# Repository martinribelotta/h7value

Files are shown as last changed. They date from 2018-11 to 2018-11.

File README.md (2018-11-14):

# STM32H7 value line small board

Simple board for stm32h750 value line device in LQFP100 package.

> Require KiCAD 5.0 or higer

#### Design rules:

- Track/Clearance width: 8mils/8mils
- Drill dia: 0.3048 mm
- Via dia: 0.4064 mm

#### Board contents:

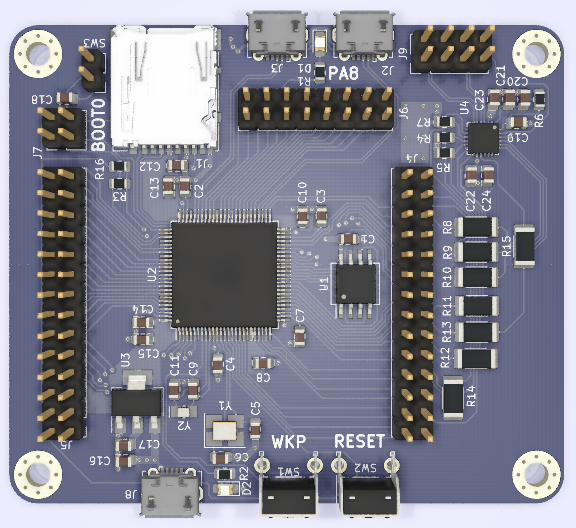
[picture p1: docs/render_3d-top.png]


- STM32H750VBT6: 1MBy RAM, 128KBy Flash at 400MHz CPU
- External flash in QSPI1 interface with execute in place (4, 8 or 16MBytes)
- USB HS and FS
- Ethernet PHY in RMII interface (optional)
- MicroSD card in 1bit interface
- 8MHz main crystal
- 32.768KHz RTC crystal
- SWD connector
- Reset button
- User button connected to PA13-WakeUP
- User led connected to PA8
- BOOT dip switch
- 800mA 3.3v regulator
- Others GPIO connected to 100mils-space pin header

#### Dimensions:

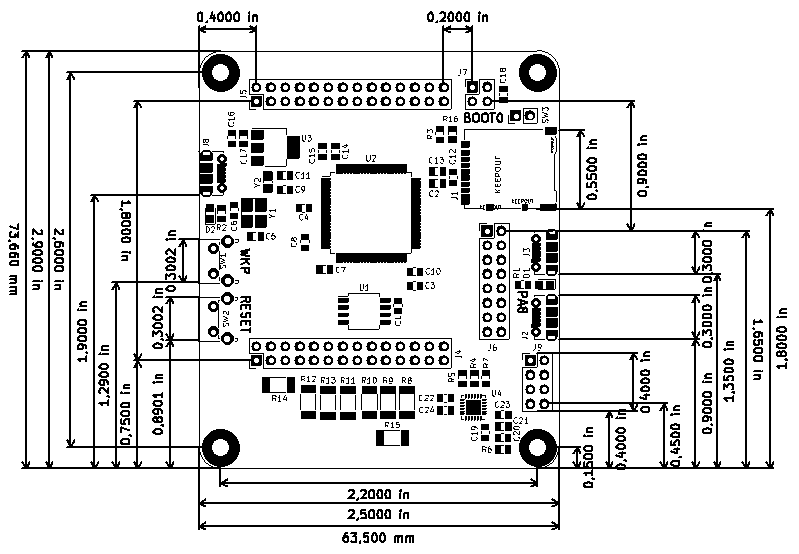
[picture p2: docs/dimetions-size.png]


#### Schematics:

Schematics

#### BOM and Gerbers

- [ ] BOM: TODO
- [ ] Gerber: TODO

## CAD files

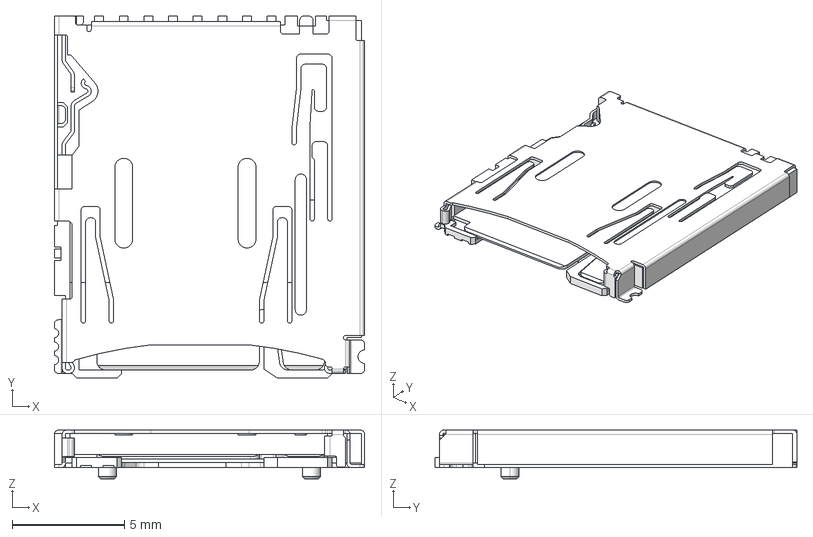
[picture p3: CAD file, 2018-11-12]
3d/DM3AT-SF-PEJ2M5.stp
13.8 x 16.2 x 2.18 mm

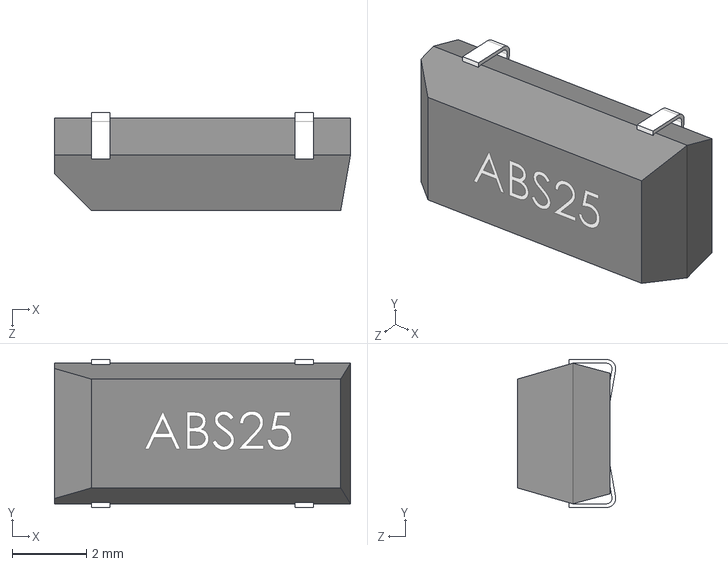
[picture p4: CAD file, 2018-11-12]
3d/ABS25.STEP
8.00 x 4.00 x 2.66 mm

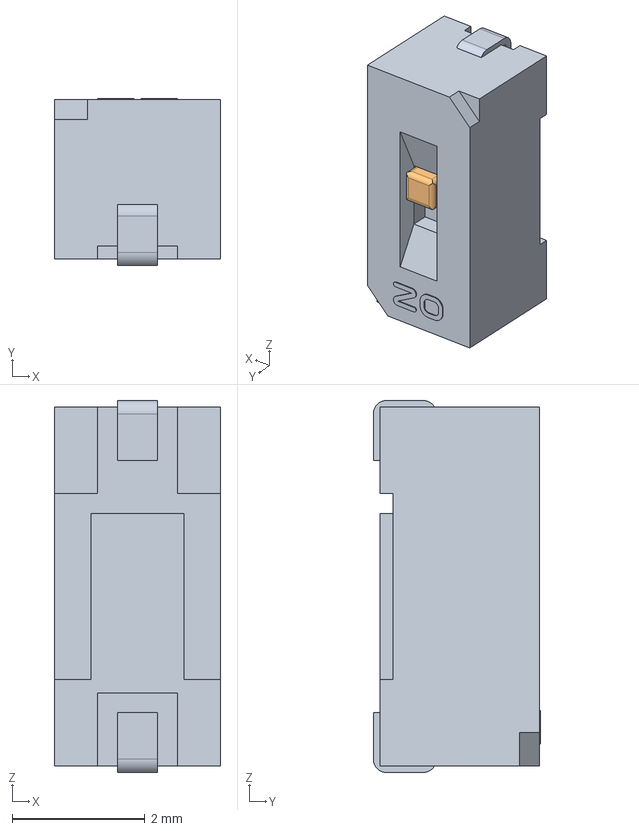
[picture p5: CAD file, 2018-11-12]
3d/CHS-01TA.stp
2.50 x 2.52 x 5.60 mm
_CHS-01-J-body
_CHS-slider

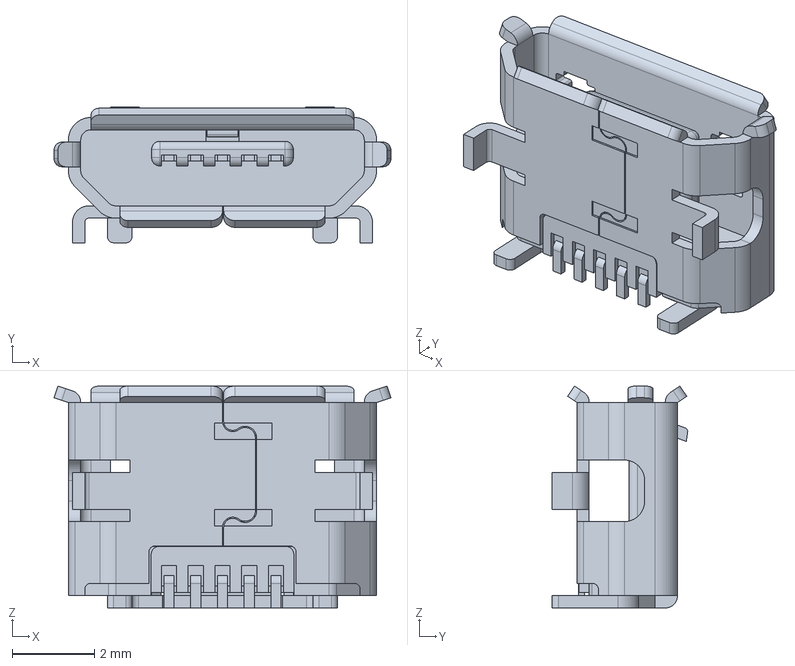
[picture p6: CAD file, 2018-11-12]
3d/1050170001.stp
8.20 x 3.30 x 5.40 mm

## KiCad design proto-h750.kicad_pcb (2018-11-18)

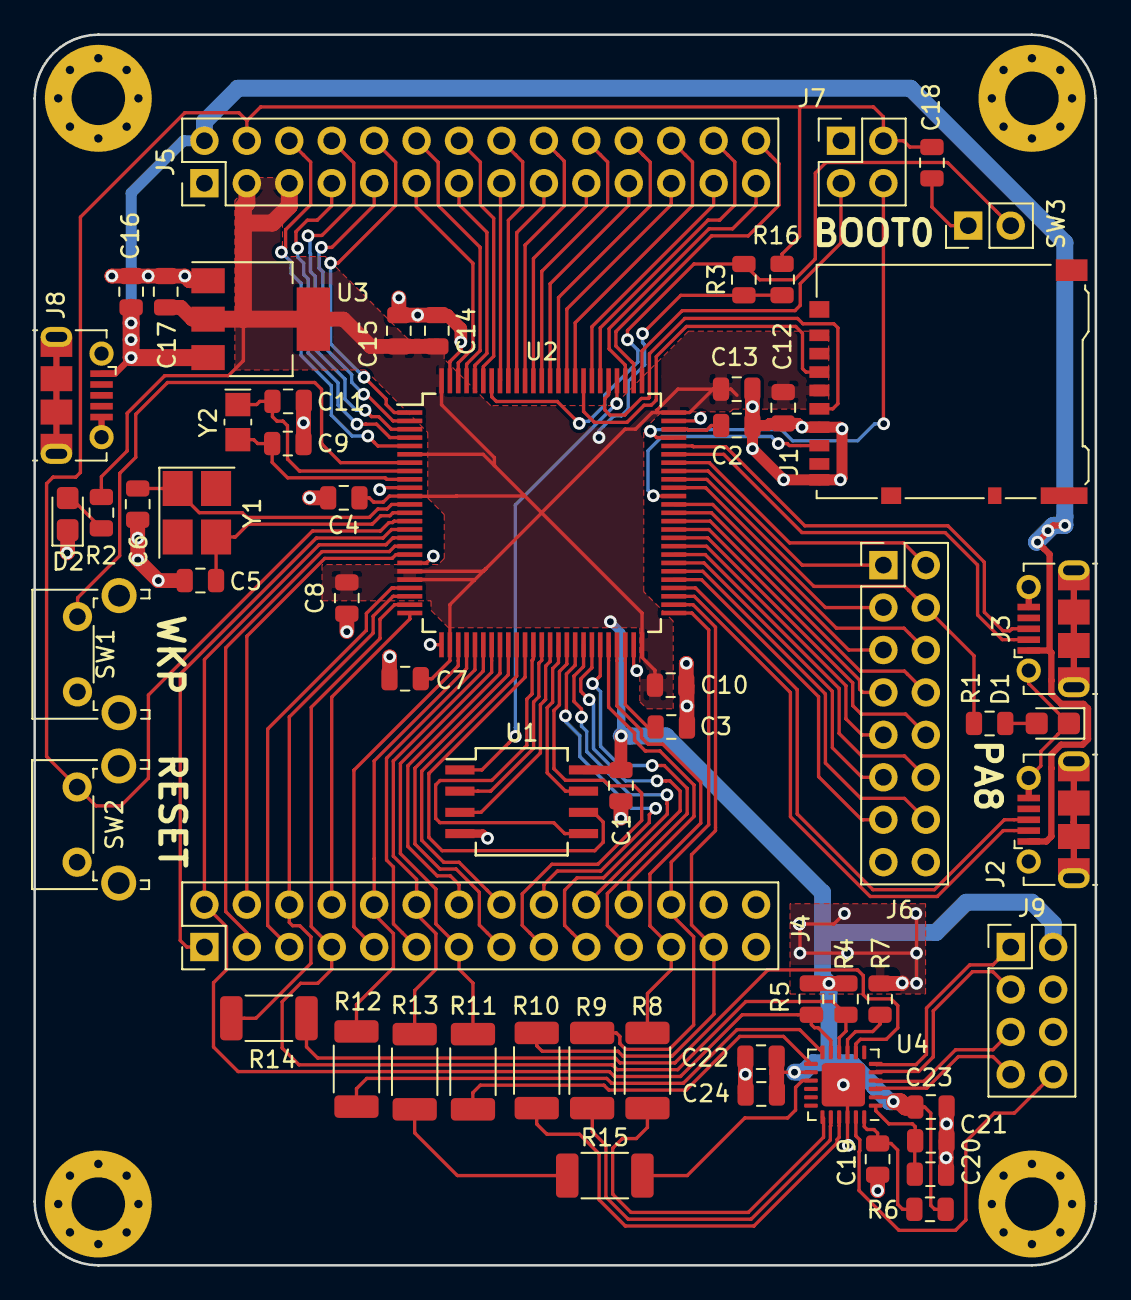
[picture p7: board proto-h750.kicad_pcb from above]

Board: 2 copper layers, 63.5 x 73.7 mm, 64 parts (0 on the bottom side), 107 nets.

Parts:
C1, C2, C3, C4, C7, C8, C10, C12, C13, C14, C18, C19, C22, C23: 100n; C_0805_2012Metric
C5, C6, C9, C11: 18p; C_0805_2012Metric
C15, C21, C24: 4.7u; C_0805_2012Metric
C16, C17: 10u; C_0805_2012Metric
C20: 2.2u; C_0805_2012Metric
D1, D2: RED; LED_0805_2012Metric_Castellated
H1, H2, H3, H4: MountingHole_Pad; MountingHole_3.2mm_M3_Pad_Via
J1: Micro_SD_Card; microSD_HC_Hirose_DM3AT-SF-PEJM5
J2, J3, J8: USB_B_Micro; USB_Micro-B_Molex-105017-0001
J4, J5: Conn_02x14_Odd_Even; PinHeader_2x14_P2.54mm_Vertical
J6: Conn_02x08_Odd_Even; PinHeader_2x08_P2.54mm_Vertical
J7: Conn_02x02_Odd_Even; PinHeader_2x02_P2.54mm_Vertical
J9: Conn_02x04_Odd_Even; PinHeader_2x04_P2.54mm_Vertical
R1, R2: 220R; R_0805_2012Metric
R3, R4, R5, R6, R16: 10K; R_0805_2012Metric
R7: 6.49K 1%; R_0805_2012Metric
R8, R9, R10, R11, R12, R13, R14, R15: 0R; R_2010_5025Metric
SW1, SW2: SW_Push; SW_Tactile_SPST_Angled_PTS645Vx31-2LFS
SW3: SW_DIP_x01; PinHeader_1x02_P2.54mm_Vertical
U1: S25FL132K0XMFI010; SO-8_5.3x6.2mm_P1.27mm
U2: STM32H750VBT6; LQFP-100_14x14mm_P0.5mm
U3: AP1117-33; SOT-223-3_TabPin2
U4: KSZ8081RNA; QFN-24-1EP_4x4mm_P0.5mm_EP2.6x2.6mm
Y1: 16MHz; Crystal_SMD_3225-4Pin_3.2x2.5mm_HandSoldering
Y2: 32.768KHz; Crystal_SMD_MicroCrystal_CC8V-T1A-2Pin_2.0x1.2mm_HandSolder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

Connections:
+5V: C16.2, J2.1, J3.1, J5.2, J8.1, U3.3
/BOOT: R3.2, SW3.2, U2.94
/ENET_CLK: R14.1, U4.8
/ENET_CRSDV: R15.2, U4.15
/ENET_MDC: J4.2, R5.2, U2.16, U4.11
/ENET_MDIO: J4.7, R4.2, U2.24, U4.10
/ENET_RXD0: R11.1, U4.13
/ENET_RXD1: R12.1, U4.12
/ENET_TXD0: R9.1, U4.20
/ENET_TXD1: R10.1, U4.21
/ENET_TXEN: R8.1, U4.19
/ETH_LED: J9.8, U4.23
/ETH_RX+: J9.5, U4.4
/ETH_RX-: J9.7, U4.3
/ETH_TX+: J9.1, U4.6
/ETH_TX-: J9.3, U4.5
/IO0: U1.5, U2.37
/IO1: U1.2, U2.38
/IO2: U1.3, U2.39
/IO3: U1.7, U2.40
/PA0: J4.5, U2.22
/PA1: J4.6, R14.2, U2.23
/PA3: J4.8, U2.25
/PA4: J4.9, U2.28
/PA5: J4.10, R12.2, U2.29
/PA6: J4.11, U2.30
/PA7: J4.12, R13.2, U2.31
/PA8: J6.4, R1.2, U2.67
/PA9: J6.1, U2.68
/PA10: J6.2, U2.69
/PA15: J5.28, U2.77
/PB0: J4.15, U2.34
/PB1: J4.16, U2.35
/PB3: J5.19, U2.89
/PB4: J5.18, U2.90
/PB5: J5.17, U2.91
/PB6: J5.16, U2.92
/PB7: J5.15, U2.93
/PB8: J5.14, U2.95
/PB9: J5.13, U2.96
/PB10: J4.22, U2.46
/PB11: J4.23, R8.2, U2.47
/PB12: J4.24, R9.2, U2.51
/PB13: J4.25, R10.2, U2.52
/PC0: J4.1, U2.15
/PC2: J4.3, U2.17
/PC3: J4.4, U2.18
/PC4: J4.13, R11.2, U2.32
/PC5: J4.14, U2.33
/PC6: J6.5, U2.63
/PC7: J6.6, U2.64
/PC9: J6.3, U2.66
/PC10: J5.27, U2.78
/PC13: SW1.2, U2.7
/PD0: J5.26, U2.81
/PD1: J5.25, U2.82
/PD3: J5.24, U2.84
/PD4: J5.23, U2.85
/PD5: J5.22, U2.86
/PD6: J5.21, U2.87
/PD7: J5.20, U2.88
/PD8: J6.13, U2.55
/PD9: J6.14, U2.56
/PD10: J6.11, U2.57
/PD11: J6.12, U2.58
/PD12: J6.9, U2.59
/PD13: J6.10, U2.60
/PD14: J6.7, U2.61
/PD15: J6.8, U2.62
/PE0: J5.12, U2.97
/PE1: J5.11, U2.98
/PE2: J5.10, U2.1
/PE3: J5.9, U2.2
/PE4: J5.8, U2.3
/PE5: J5.7, U2.4
/PE6: J5.6, U2.5
/PE11: J4.17, U2.41
/PE12: J4.18, U2.42
/PE13: J4.19, U2.43
/PE14: J4.20, U2.44
/PE15: J4.21, U2.45
/SCLK: U1.6, U2.36
/SD_CK: J1.5, U2.80
/SD_CMD: J1.3, U2.83
/SD_D0: J1.7, U2.65
/SWCLK: J7.3, U2.76
/SWDIO: J7.4, U2.72
/USB0_D+: J2.3, U2.54
/USB0_D-: J2.2, U2.53
/USB1_D+: J3.3, U2.71
/USB1_D-: J3.2, U2.70
/nCS: U1.1, U2.79
/nRESET: C18.1, J5.4, J7.2, R16.2, SW2.2, U2.14
GND: C1.2, C2.2, C3.2, C4.2, C5.1, C6.1, C7.2, C8.2, C9.1, C10.2, C11.1, C12.2, C13.2, C14.1, C15.2, C16.1, C17.2, C18.2, C19.1, C20.1, C21.1, C22.1, C23.1, C24.1, D1.1, D2.1, H1.1, H2.1, H3.1, H4.1, J1.6, J1.9, J2.5, J2.6, J3.5, J3.6, J4.26, J4.27, J4.28, J5.1, J6.15, J6.16, J7.1, J8.5, J8.6, J9.4, J9.6, R7.1, SW1.1, SW2.1, SW3.1, U1.4, U2.10, U2.19, U2.26, U2.49, U2.74, U2.99, U3.1, U4.22, U4.25
unnamed: C2.1, U2.73
unnamed: C3.1, U2.48
unnamed: C5.2, U2.13, Y1.3
unnamed: C6.2, U2.12, Y1.1
unnamed: C9.2, U2.9, Y2.2
unnamed: C11.2, U2.8, Y2.1
unnamed: C19.2, R6.2, U4.24
unnamed: C20.2, C21.2, U4.1
unnamed: D1.2, R1.1
unnamed: D2.2, R2.1
unnamed: R7.2, U4.9
unnamed: R13.1, R15.1
VCC: C1.1, C4.1, C7.1, C8.1, C10.1, C12.1, C13.1, C14.2, C15.1, C17.1, C22.2, C23.2, C24.2, J1.4, J5.3, J5.5, J9.2, R2.2, R3.1, R4.1, R5.1, R6.1, R16.1, U1.8, U2.6, U2.11, U2.20, U2.21, U2.27, U2.50, U2.75, U2.100, U3.2, U4.2, U4.14

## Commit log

2018-11-14 Add eth phy
    [proto-h750.kicad_pcb, proto-h750.sch]
2018-11-14 Add README, create schematics and put measures in PCB
    [proto-h750.kicad_pcb]
2018-11-16 Change dimention annotations
    [proto-h750.kicad_pcb]
2018-11-18 Prepare to BOM
    - Change BOOT switch by jumper
    - Change 32.768KHz footprint by 2SMD 2.0x1.2mm
    - Change 8MHz 4SMD by same footprint in 16MHz
    - Add Part number field of all schematic items
    [proto-h750.kicad_pcb, proto-h750.sch]
2018-11-18 Prepare to BOM (2)
    - Change resistor of 22R in ETH PHY by 0R
    [proto-h750.sch]
2018-11-18 Prepare to BOM (3)
    - Add pull-up on reset
    - Generate Gerbers in protel format-name
    [proto-h750-B.Cu.gbl, proto-h750-B.Mask.gbs, proto-h750-B.Paste.gbp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]
